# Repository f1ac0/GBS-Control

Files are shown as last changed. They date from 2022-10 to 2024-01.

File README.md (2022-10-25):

# GBS-control
GBS-control, https://github.com/ramapcsx2/gbs-control, is an alternative firmware for Tvia Trueview5725 based upscalers / video converter boards such as the "GBS8200".

This repository contains the boards I designed to improve my own GBS-8200 with GBS-control using ESP12/ESP-M2 modules.

# Disclaimer
This is a hobbyist project, it comes with no warranty and no support.

This board is not endorsed by firmware author, please don't bother him with issues you might have because of it.

I publish my work under the CC-BY-NC-SA license.

If you find it useful and want to reward my hard work : I am always looking for Amiga/Amstrad CPC hardware to repair and hack, please contact me.

# BOM
- 1x ESP12 or ESP-M2 module
- 1x PLCC-44 through-hole socket
- 1x 10uF 0805 capacitor
- 2x 100nF 0805 capacitors (the one on EN might be omitted)
- 4x 10K 0805 resistors (the ones on GPIO0 and GPIO0 might be omitted)

# Making it
The socket must be prepared before soldering : remove the 4 small stands inside the socket and file plastic from its top up to the contacts so the socket can plug on top of the PLCC chip without popping out. Be careful to remove plastic debris, and check its orientation before soldering under the PCB.

Check for shorts at least between power traces before applying power !

The programming port does not need to be soldered since it needs to be programmed just once : you can just hold it in place during the few seconds required for programming with an USB to serial adapter. When you want to program it, remember to short GPIO0 to ground before applying power.

# Using it
Plug the GBS-control board on the PLCC controller. Connect the clock generator board on the clock port.

There is no need to populate P8 since it is shorted by the board. It also takes the 3.3V from the PLCC chip so no additional power connection is required.

See GBS-control wiki for software setup.

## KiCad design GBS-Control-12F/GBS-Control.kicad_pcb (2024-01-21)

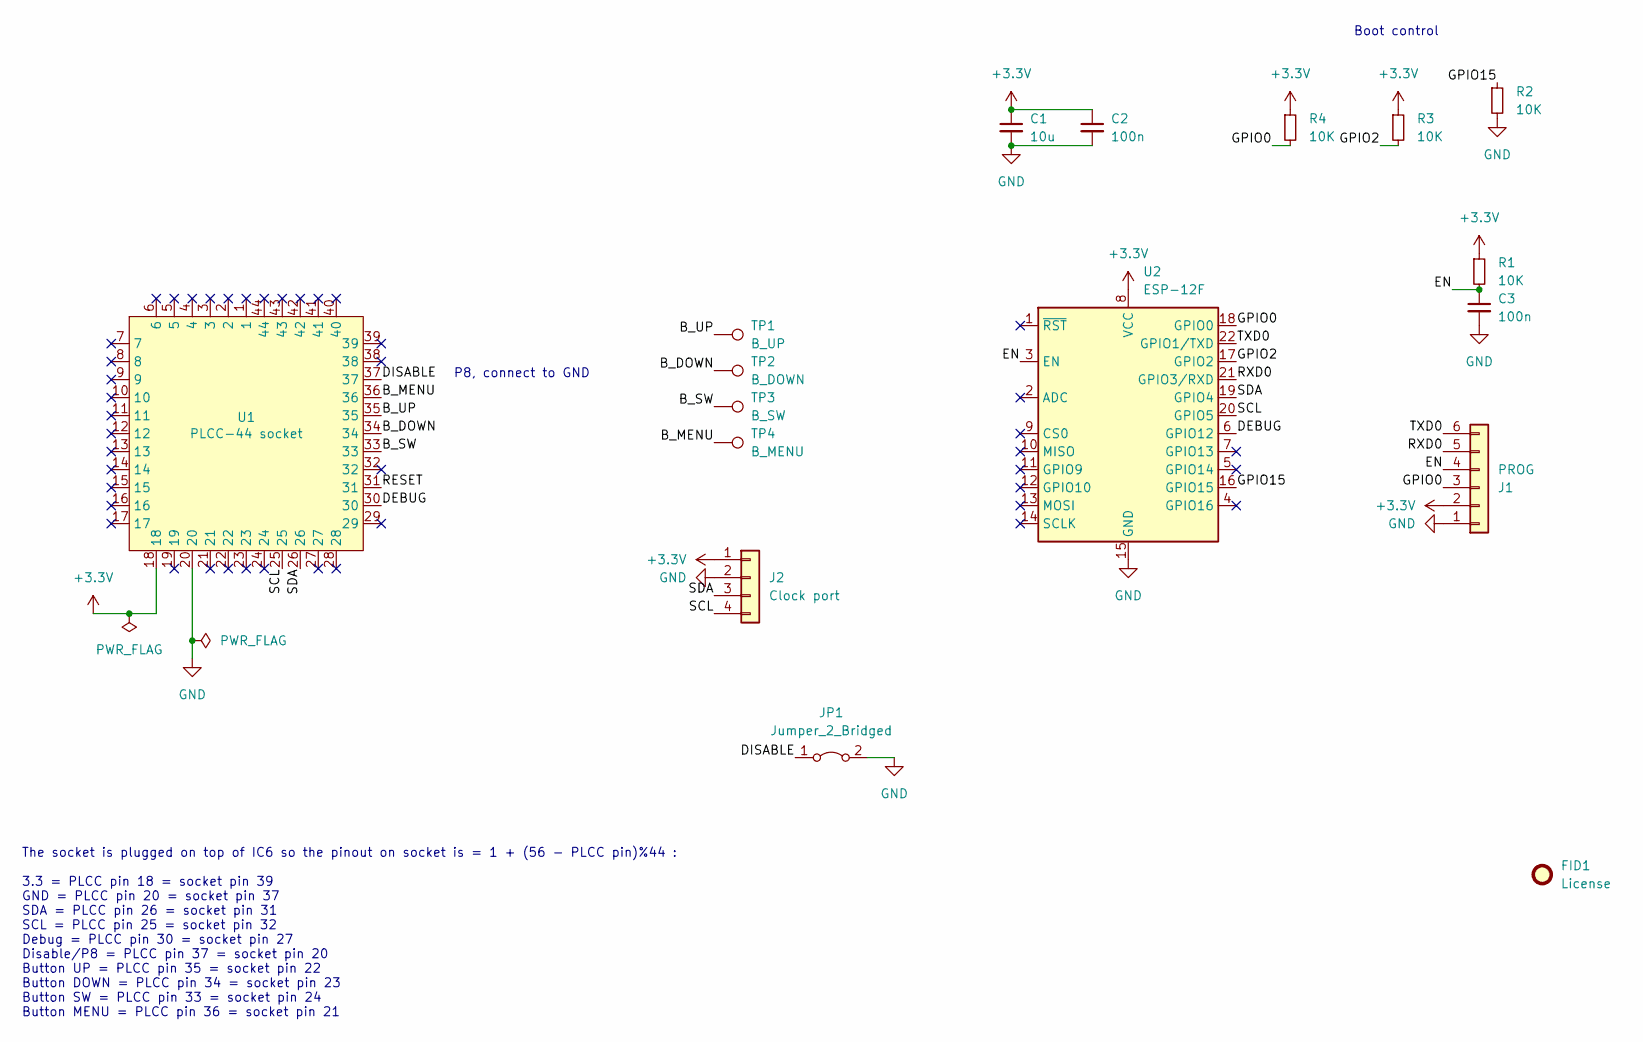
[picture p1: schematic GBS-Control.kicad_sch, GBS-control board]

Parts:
C1: 10u; C_0805_2012Metric
C2, C3: 100n; C_0805_2012Metric
FID1: License; CC_BY_NC_SA_long_silkscreen
J1: PROG; PinSocket_1x06_P2.54mm_Vertical
J2: Clock port; PinHeader_1x04_P2.54mm_Vertical
JP1: Jumper_2_Bridged; SolderJumper-2_P1.3mm_Bridged_RoundedPad1.0x1.5mm
R1, R2, R3, R4: 10K; R_0805_2012Metric
TP1: B_UP; TestPoint_Pad_D1.0mm
TP2: B_DOWN; TestPoint_Pad_D1.0mm
TP3: B_SW; TestPoint_Pad_D1.0mm
TP4: B_MENU; TestPoint_Pad_D1.0mm
U1: PLCC-44 socket; PLCC-44_THT-SocketOnTop
U2: ESP-12F; ESP-12E_No-bottom-pins

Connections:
+3.3V: C1.1, C2.1, J1.2, J2.1, R1.1, R3.1, R4.1, U1.18, U2.8 (VCC)
/B_DOWN: TP2.1, U1.34
/B_MENU: TP4.1, U1.36
/B_SW: TP3.1, U1.33
/B_UP: TP1.1, U1.35
/DEBUG: U1.30, U2.6 (GPIO12)
/DISABLE: JP1.1 (A), U1.37
/EN: C3.1, J1.4, R1.2, U2.3 (EN)
/GPIO0: J1.3, R4.2, U2.18 (GPIO0)
/GPIO2: R3.2, U2.17 (GPIO2)
/GPIO15: R2.1, U2.16 (GPIO15)
/RESET: U1.31
/RXD0: J1.5, U2.21 (GPIO3/RXD)
/SCL: J2.4, U1.25, U2.20 (GPIO5)
/SDA: J2.3, U1.26, U2.19 (GPIO4)
/TXD0: J1.6, U2.22 (GPIO1/TXD)
GND: C1.2, C2.2, C3.2, J1.1, J2.2, JP1.2 (B), R2.2, U1.20, U2.15 (GND)

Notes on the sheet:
Boot control
P8, connect to GND
The socket is plugged on top of IC6 so the pinout on socket is = 1 + (56 - PLCC pin)%44 : 3.3 = PLCC pin 18 = socket pin 39 GND = PLCC pin 20 = socket pin 37 SDA = PLCC pin 26 = socket pin 31 SCL = PLCC pin 25 = socket pin 32 Debug = PLCC pin 30 = socket pin 27 Disable/P8 = PLCC pin 37 = socket pin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

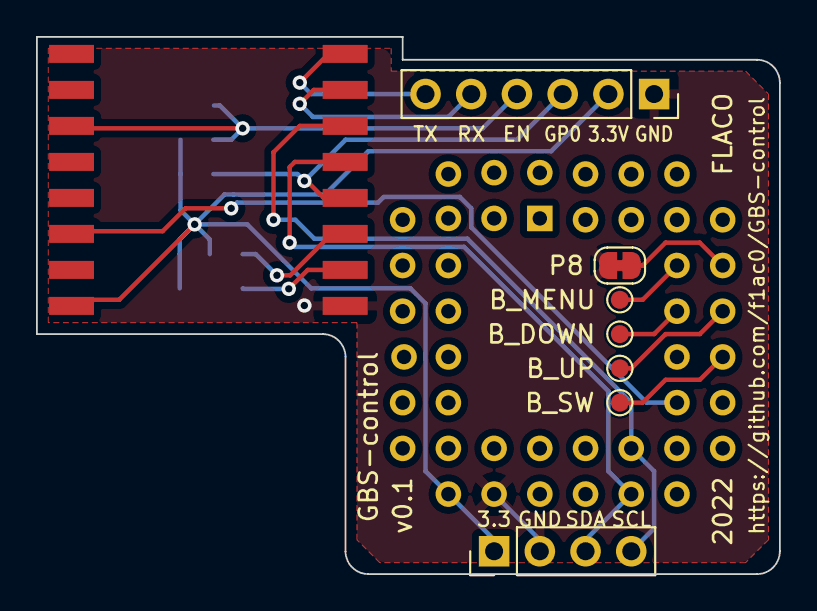
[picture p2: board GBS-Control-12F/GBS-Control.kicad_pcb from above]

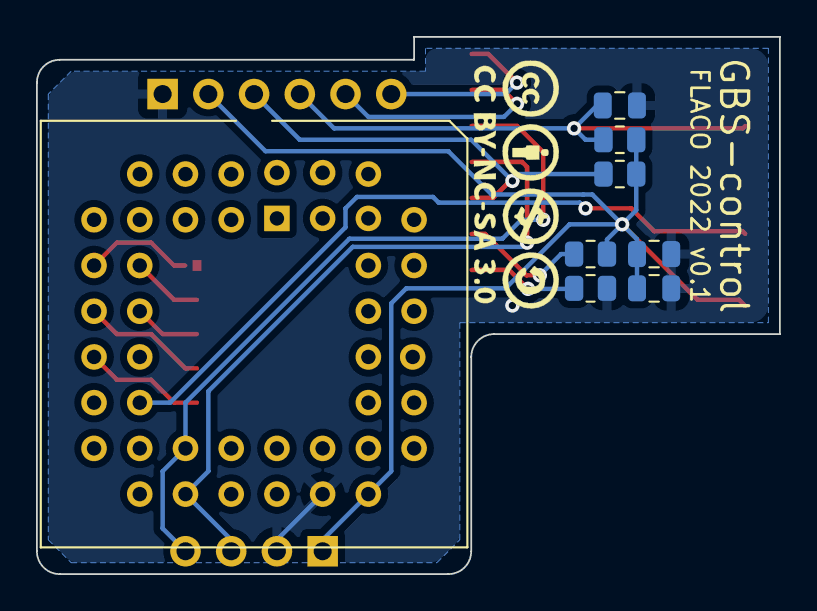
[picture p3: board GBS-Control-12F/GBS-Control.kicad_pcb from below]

Board: 2 copper layers, 41.3 x 29.8 mm, 17 parts (9 on the bottom side), 16 nets.

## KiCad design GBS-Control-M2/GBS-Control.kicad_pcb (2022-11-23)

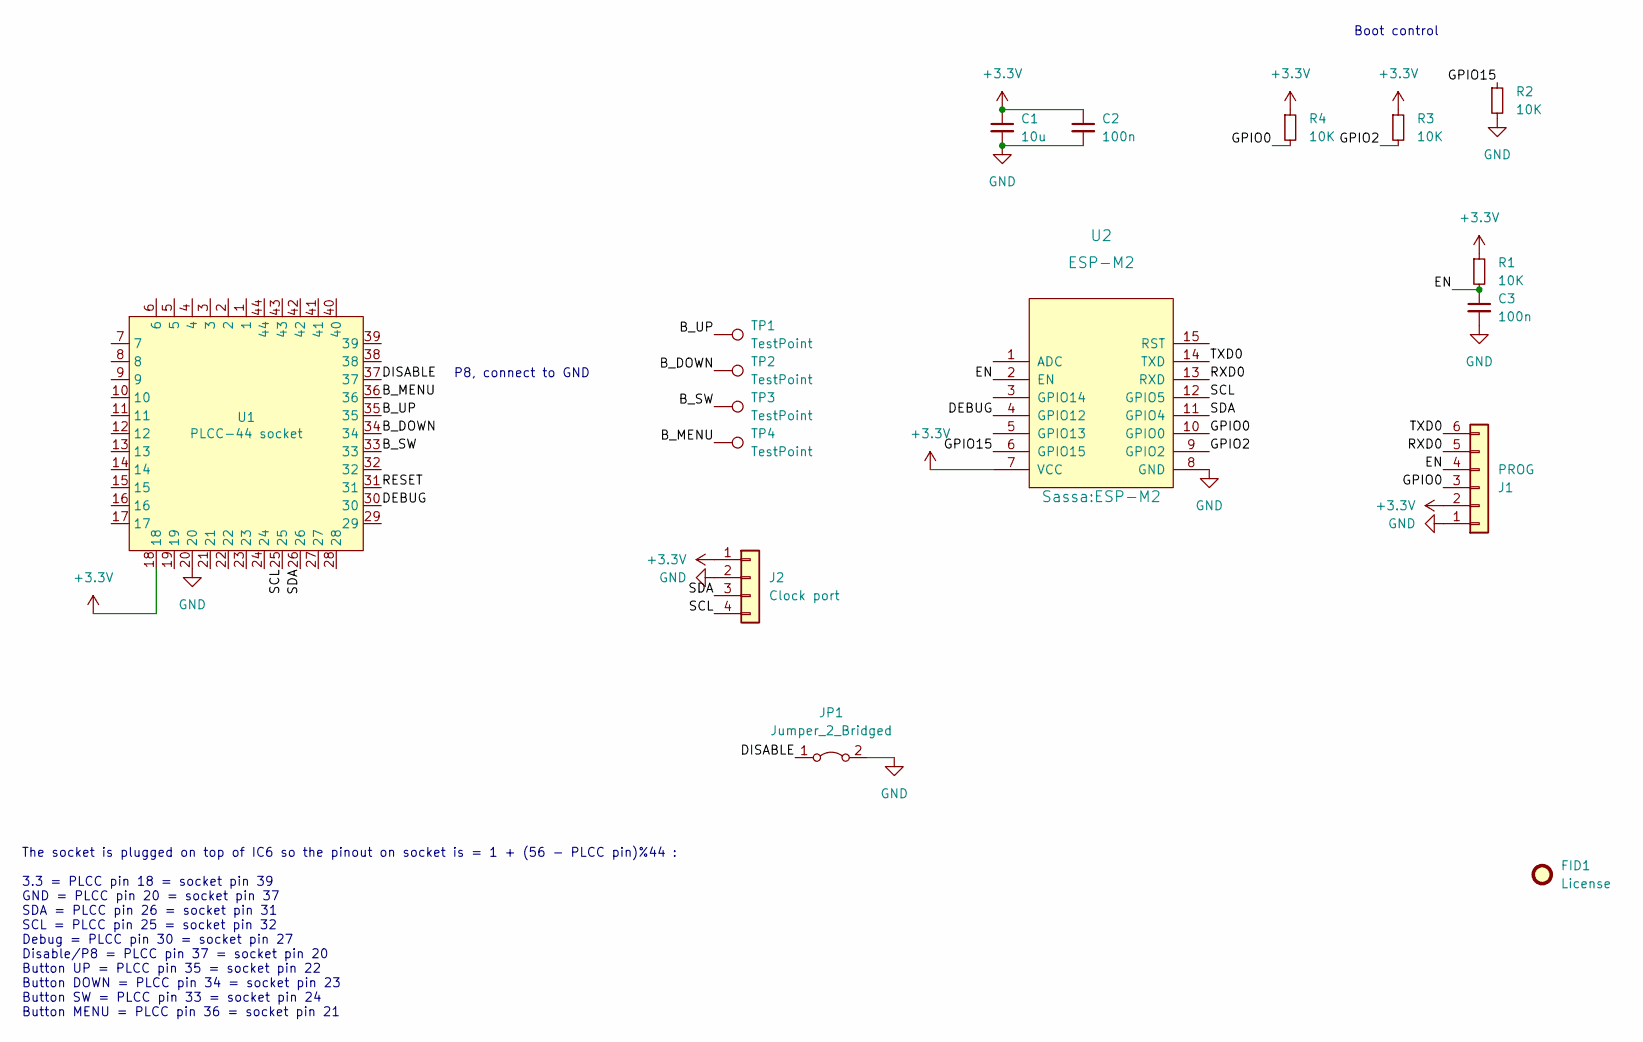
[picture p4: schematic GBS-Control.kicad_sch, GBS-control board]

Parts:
C1: 10u; C_0805_2012Metric
C2, C3: 100n; C_0805_2012Metric
FID1: License; CC_BY_NC_SA_square_silkscreen_4.8x4.8mm
J1: PROG; PinSocket_1x06_P2.54mm_Vertical
J2: Clock port; PinHeader_1x04_P2.54mm_Vertical
JP1: Jumper_2_Bridged; SolderJumper-2_P1.3mm_Bridged_RoundedPad1.0x1.5mm
R1, R2, R3, R4: 10K; R_0805_2012Metric
TP1, TP2, TP3, TP4: TestPoint; TestPoint_Pad_D1.0mm
U1: PLCC-44 socket; PLCC-44_THT-SocketOnTop
U2: ESP-M2

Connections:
+3.3V: C1.1, C2.1, J1.2, J2.1, R1.1, R3.1, R4.1, U1.18, U2.7 (VCC)
/B_DOWN: TP2.1, U1.34
/B_MENU: TP4.1, U1.36
/B_SW: TP3.1, U1.33
/B_UP: TP1.1, U1.35
/DEBUG: U1.30, U2.4 (GPIO12)
/DISABLE: JP1.1 (A), U1.37
/EN: C3.1, J1.4, R1.2, U2.2 (EN)
/GPIO0: J1.3, R4.2, U2.10 (GPIO0)
/GPIO2: R3.2, U2.9 (GPIO2)
/GPIO15: R2.1, U2.6 (GPIO15)
/RESET: U1.31
/RXD0: J1.5, U2.13 (RXD)
/SCL: J2.4, U1.25, U2.12 (GPIO5)
/SDA: J2.3, U1.26, U2.11 (GPIO4)
/TXD0: J1.6, U2.14 (TXD)
GND: C1.2, C2.2, C3.2, J1.1, J2.2, JP1.2 (B), R2.2, U1.20, U2.8 (GND)

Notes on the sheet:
Boot control
P8, connect to GND
The socket is plugged on top of IC6 so the pinout on socket is = 1 + (56 - PLCC pin)%44 : 3.3 = PLCC pin 18 = socket pin 39 GND = PLCC pin 20 = socket pin 37 SDA = PLCC pin 26 = socket pin 31 SCL = PLCC pin 25 = socket pin 32 Debug = PLCC pin 30 = socket pin 27 Disable/P8 = PLCC pin 37 = socket pin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

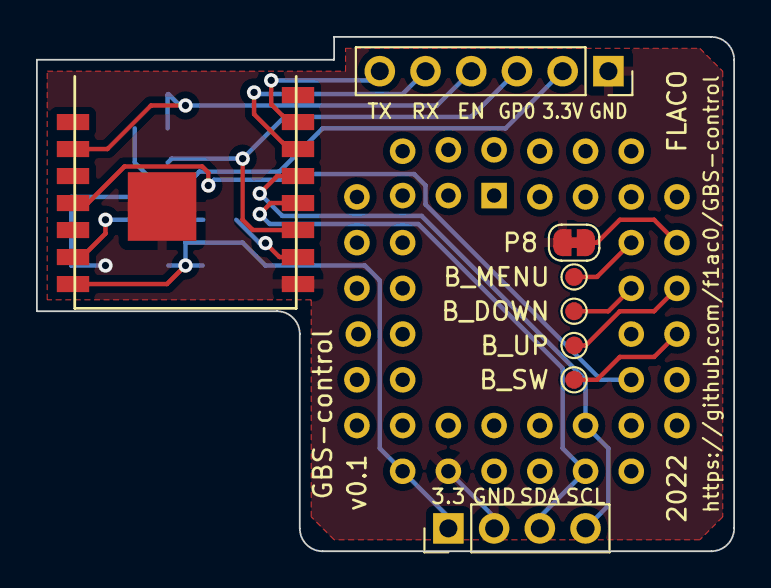
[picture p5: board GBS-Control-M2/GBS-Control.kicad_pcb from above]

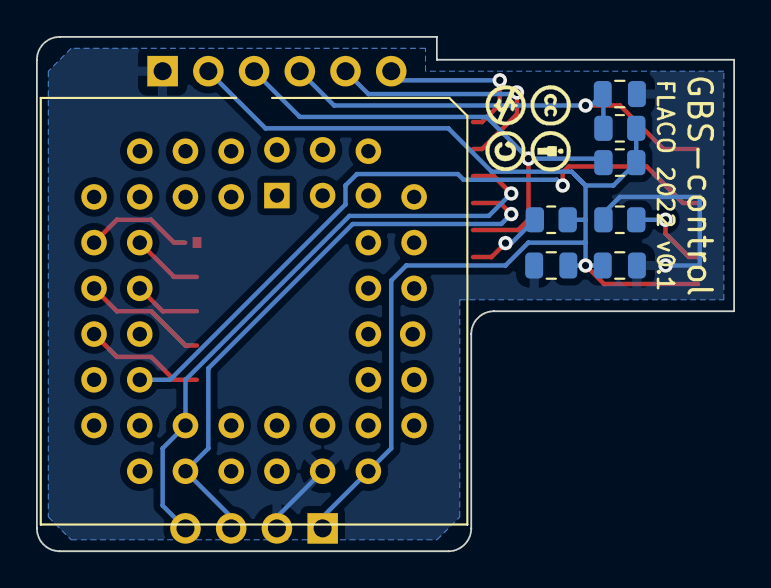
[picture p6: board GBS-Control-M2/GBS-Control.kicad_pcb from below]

Board: 2 copper layers, 38.7 x 28.6 mm, 17 parts (9 on the bottom side), 16 nets.

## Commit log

2022-10-23 Repository init with KiCAD boards, Readme and license
    [GBS-Control.kicad_pcb, GBS-Control.kicad_sch]
2022-10-25 KiCAD : add a port to connect the Si5351 Clock Generator
    [GBS-Control.kicad_pcb, GBS-Control.kicad_sch]
2022-11-23 GBS-Control-12F, GBS-Control-M2 : update socket symbol and footprint, no PCB change
    [GBS-Control.kicad_pcb, GBS-Control.kicad_sch]
2024-01-21 GBS-Control-12F, GBS-Control-M2 : update ibom ; small silkscreen change
    [GBS-Control.kicad_pcb, GBS-Control.kicad_sch]

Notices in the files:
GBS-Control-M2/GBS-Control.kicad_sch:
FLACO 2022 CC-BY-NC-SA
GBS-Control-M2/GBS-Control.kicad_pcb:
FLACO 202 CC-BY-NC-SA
